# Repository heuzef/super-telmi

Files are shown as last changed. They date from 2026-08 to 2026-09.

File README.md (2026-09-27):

<div align="center">

Logo Super Telmi

 

</div>

---

<details open>
<summary><h3>🇫🇷&nbsp; Français</h3></summary>

<br>

# Super Telmi, la super machine pour Telmi

## Qu’est-ce que la Super Telmi ?

La Super Telmi est une boîte à histoires Open-Source conçue pour émerveiller les enfants, basée sur le système libre [Telmi](https://telmi.fr).

Elle s’appuie sur la console Miyoo, reconnue pour sa simplicité, son prix abordable et sa robustesse, idéale pour les réparations et les améliorations.

Des parents passionnés ont imaginé et testé des améliorations pour offrir le meilleur à leurs enfants.

La Super Telmi rassemble ces innovations et les retours d’expérience concrets des enfants, pour une expérience toujours plus enrichissante.

🎬 [Voir la vidéo de présentation de la Super Telmi](https://www.youtube.com/watch?v=lRGE3fMTku0)

Aperçu de la coque Super Telmi

## Qu’apporte-t-elle de plus ?

* 🔊 **Un vrai haut-parleur de 40 mm**, à la place du minuscule composant d’origine à la qualité sonore décevante.
* 🛡️ **Une coque imprimée en TPU souple**, qui encaisse les chocs, les chutes et les crises de colère.
* 🧲 **Une station d’accueil magnétique**, pour recharger l’appareil d’un simple geste, sans manipuler de connecteur.
* ✂️ **Une simplification du matériel** : les gâchettes, inutiles pour Telmi, sont supprimées.

## Comment se la procurer ?

La Super Telmi est accessible à tous : fabriquez-la vous-même ! Les plans et manuels de fabrication [sont disponibles ici](./diy/DIY_FR.md).

À prévoir pour une fabrication maison : une Miyoo Mini Plus, du matériel de soudure, une imprimante 3D et quelques composants détaillés dans le guide. Comptez environ **20 heures d’impression** au total (≈ 9 h pour la coque, ≈ 10 h pour la station d’accueil).

## Contenu du dépôt

| Dossier | Contenu |
| --- | --- |
| [`diy/`](./diy/) | Les guides de fabrication pas à pas, en [français](./diy/DIY_FR.md), [anglais](./diy/DIY_EN.md), [espagnol](./diy/DIY_ES.md) et [chinois](./diy/DIY_ZH.md). |
| [`files/`](./files/) | Les fichiers 3D : sources CAO (`.f3d`, `.step`), modèles `.3mf`, et fichiers prêts à imprimer pour certaines imprimantes. |

## Contribuer

La Super Telmi a pour vocation d'être en constante amélioration grâce aux idées des parents et enfants.
Il est possible d'apporter votre contribution en [rejoignant le Discord de la communauté Telmi](https://discord.gg/ZTA5FyERbg).

> Les guides existent en plusieurs langues : toute modification apportée à [`DIY_FR.md`](./diy/DIY_FR.md) doit être répercutée dans toutes les autres versions, et inversement.

## Licence

Ce projet est publié sous licence **[CC BY-NC-SA 4.0](./LICENCE.md)** : partage et modifications libres avec attribution, mais **usage commercial interdit sans autorisation préalable**.

</details>

<details>
<summary><h3>🇬🇧&nbsp; English</h3></summary>

<br>

# Super Telmi, the super machine for Telmi

## What is Super Telmi?

Super Telmi is an open-source story box designed to amaze children, based on the free [Telmi](https://telmi.fr) system.

It uses the Miyoo console, known for its simplicity, affordability, and robustness, making it ideal for repairs and upgrades.

Passionate parents have imagined and tested improvements to offer the best for their children.

Super Telmi combines these innovations with real-life feedback from children, for an even more enriching experience.

🎬 [Watch the Super Telmi presentation video](https://www.youtube.com/watch?v=lRGE3fMTku0) (in French)

Preview of the Super Telmi case

## What does it add?

* 🔊 **A real 40 mm speaker**, replacing the tiny original component and its disappointing sound quality.
* 🛡️ **A flexible TPU-printed shell**, which absorbs knocks, drops and temper tantrums.
* 🧲 **A magnetic docking station**, to charge the device in a single gesture, with no connector to fiddle with.
* ✂️ **Simplified hardware**: the triggers, useless for Telmi, are removed.

## How to get it?

Super Telmi is accessible to everyone: do it yourself! Plans and manuals [are available here](./diy/DIY_EN.md).

What you need for a home build: a Miyoo Mini Plus, soldering equipment, a 3D printer and a few components detailed in the guide. Expect around **20 hours of printing** in total (~9h for the shell, ~10h for the docking station).

## Repository contents

| Folder | Contents |
| --- | --- |
| [`diy/`](./diy/) | The step-by-step build guides, in [French](./diy/DIY_FR.md), [English](./diy/DIY_EN.md), [Spanish](./diy/DIY_ES.md) and [Chinese](./diy/DIY_ZH.md). |
| [`files/`](./files/) | The 3D files: CAD sources (`.f3d`, `.step`), `.3mf` models, and ready-to-print files for some printers. |

## Contribute

Super Telmi aims to be constantly improved thanks to the ideas of parents and children.
You can contribute [by joining the Telmi community Discord](https://discord.gg/ZTA5FyERbg).

> The guides exist in several languages: any change made to [`DIY_EN.md`](./diy/DIY_EN.md) must be mirrored in every other version, and vice versa.

## Licence

This project is released under the **[CC BY-NC-SA 4.0](./LICENCE.md)** licence: sharing and modifications are free with attribution, but **commercial use is forbidden without prior permission**.

</details>

<details>
<summary><h3>🇪🇸&nbsp; Español</h3></summary>

<br>

# Super Telmi, la súper máquina para Telmi

## ¿Qué es la Super Telmi?

La Super Telmi es una caja de cuentos de código abierto concebida para maravillar a los niños, basada en el sistema libre [Telmi](https://telmi.fr).

Se apoya en la consola Miyoo, reconocida por su simplicidad, su precio asequible y su robustez, ideal para las reparaciones y las mejoras.

Unos padres apasionados han imaginado y probado mejoras para ofrecer lo mejor a sus hijos.

La Super Telmi reúne estas innovaciones y los comentarios concretos de los niños, para una experiencia cada vez más enriquecedora.

🎬 [Ver el vídeo de presentación de la Super Telmi](https://www.youtube.com/watch?v=lRGE3fMTku0) (en francés)

Vista previa de la carcasa de la Super Telmi

## ¿Qué aporta de más?

* 🔊 **Un altavoz de verdad de 40 mm**, en lugar del minúsculo componente original de calidad de sonido decepcionante.
* 🛡️ **Una carcasa impresa en TPU flexible**, que aguanta los golpes, las caídas y las rabietas.
* 🧲 **Una base de carga magnética**, para recargar el aparato con un simple gesto, sin manipular ningún conector.
* ✂️ **Una simplificación del material**: los gatillos, inútiles para Telmi, se eliminan.

## ¿Cómo conseguirla?

La Super Telmi está al alcance de todos: ¡fabrícala tú mismo! Los planos y manuales de fabricación [están disponibles aquí](./diy/DIY_ES.md).

Lo que hay que prever para una fabricación casera: una Miyoo Mini Plus, material de soldadura, una impresora 3D y algunos componentes detallados en la guía. Cuenta con unas **20 horas de impresión** en total (≈ 9 h para la carcasa, ≈ 10 h para la base de carga).

## Contenido del repositorio

| Carpeta | Contenido |
| --- | --- |
| [`diy/`](./diy/) | Las guías de fabricación paso a paso, en [francés](./diy/DIY_FR.md), [inglés](./diy/DIY_EN.md), [español](./diy/DIY_ES.md) y [chino](./diy/DIY_ZH.md). |
| [`files/`](./files/) | Los archivos 3D: fuentes CAD (`.f3d`, `.step`), modelos `.3mf` y archivos listos para imprimir para algunas impresoras. |

## Contribuir

La Super Telmi tiene la vocación de mejorar constantemente gracias a las ideas de los padres y de los niños.
Puedes aportar tu contribución [uniéndote al Discord de la comunidad Telmi](https://discord.gg/ZTA5FyERbg).

> Las guías existen en varios idiomas: cualquier modificación realizada en [`DIY_ES.md`](./diy/DIY_ES.md) debe replicarse en todas las demás versiones, y a la inversa.

## Licencia

Este proyecto se publica bajo licencia **[CC BY-NC-SA 4.0](./LICENCE.md)**: compartir y modificar libremente con atribución, pero **uso comercial prohibido sin autorización previa**.

</details>

<details>
<summary><h3>🇨🇳&nbsp; 中文</h3></summary>

<br>

# Super Telmi，为 Telmi 打造的超级机器

## 什么是 Super Telmi？

Super Telmi 是一款开源故事机，基于自由系统 [Telmi](https://telmi.fr)，旨在带给孩子们惊喜。

它以 Miyoo 掌机为基础，这款掌机以简单、价格实惠和坚固耐用著称，非常适合维修和改装。

一群充满热情的家长构想并测试了各种改进，只为给自己的孩子最好的。

Super Telmi 汇集了这些创新，以及孩子们在实际使用中的反馈，带来愈发丰富的体验。

🎬 [观看 Super Telmi 介绍视频](https://www.youtube.com/watch?v=lRGE3fMTku0)（法语）

Super Telmi 外壳预览

## 它有哪些提升？

* 🔊 **一只真正的 40 mm 扬声器**，取代音质令人失望的原装微型元件。
* 🛡️ **柔性 TPU 打印外壳**，能够承受磕碰、跌落和闹脾气。
* 🧲 **磁吸充电底座**，一个动作即可充电，无需插拔接头。
* ✂️ **精简硬件**：Telmi 用不到的扳机键已被移除。

## 如何获得？

Super Telmi 人人可得：自己动手做吧！图纸和制作手册[可在此处获取](./diy/DIY_ZH.md)。

自行制作需要准备：一台 Miyoo Mini Plus、焊接工具、一台 3D 打印机，以及指南中详细列出的若干元件。全部打印时间约为 **20 小时**（外壳约 9 小时，充电底座约 10 小时）。

## 仓库内容

| 目录 | 内容 |
| --- | --- |
| [`diy/`](./diy/) | 分步制作指南，提供[法语](./diy/DIY_FR.md)、[英语](./diy/DIY_EN.md)、[西班牙语](./diy/DIY_ES.md)和[中文](./diy/DIY_ZH.md)版本。 |
| [`files/`](./files/) | 3D 文件：CAD 源文件（`.f3d`、`.step`）、`.3mf` 模型，以及部分打印机的即打即用文件。 |

## 参与贡献

Super Telmi 立志依靠家长和孩子们的想法不断改进。
欢迎[加入 Telmi 社区 Discord](https://discord.gg/ZTA5FyERbg) 参与贡献。

> 本指南提供多个语言版本：对 [`DIY_ZH.md`](./diy/DIY_ZH.md) 所做的任何修改都必须同步到其他所有语言版本，反之亦然。

## 许可协议

本项目基于 **[CC BY-NC-SA 4.0](./LICENCE.md)** 许可协议发布：可自由分享和修改，但须署名，且**未经事先许可禁止商业使用**。

</details>

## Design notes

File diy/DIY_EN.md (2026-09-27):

<!-- This guide exists in several languages. Any change made here must be mirrored in DIY_FR.md, DIY_ES.md and DIY_ZH.md. -->

Welcome to the Super Telmi build guide. You are about to give your children the very best storytelling box there is not only because of the love you will put into making them this beautiful gift, but also because of the outstanding durability of the hardware offered here, as well as the unlimited potential offered by Telmi.

# Required equipment

* Electronic soldering equipment
* 3D printer
* [A Miyoo Mini Plus](https://wiki.telmi.fr/achats/miyoo_mini_plus)

# Parts to buy
* [40 mm 8 ohm 3 W speaker](https://fr.aliexpress.com/item/1005002679785627.html)
* [Electrical wire](https://fr.aliexpress.com/item/1005005450270866.html)
* [M2 and M3 screws and nuts](https://fr.aliexpress.com/item/1005007159750547.html)
* [250 g spool of TPU filament](https://fr.aliexpress.com/item/1005007707597137.html)
* [Cable with magnetic USB-C tip](https://fr.aliexpress.com/item/1005009401790316.html)
* [4 round neodymium magnets, 10x3 mm](https://fr.aliexpress.com/item/1005009749865836.html)
* [Cyanoacrylate glue](https://fr.aliexpress.com/item/1005008517608338.html)
* [Cable ties](https://fr.aliexpress.com/item/1005009405351665.html)

# Build

Feel free to come and meet the community on [Discord](https://discord.gg/ZTA5FyERbg) before you start building!

Your feedback is invaluable in helping this project improve continuously.

## 3D printing the parts



The 3D files are available [HERE](../files/) and must be printed in TPU for shock absorption.

For the main shell, an infill of at least 25% to 30% is recommended to make sure the Super Telmi is as resistant as possible to knocks, drops, temper tantrums, or any other creative misuse aimed at doing violence to a sibling.

A higher infill would risk making the shell too rigid, and therefore less effective at absorbing impacts.

## Disassembling the Miyoo

The first step is to remove the battery, through the small hatch at the back of the Miyoo.
It comes out fairly easily using small pliers, gently pull out the 2-pin connector.

Let's start taking off the Miyoo's back shell. You will spot 6 small M2 screws.

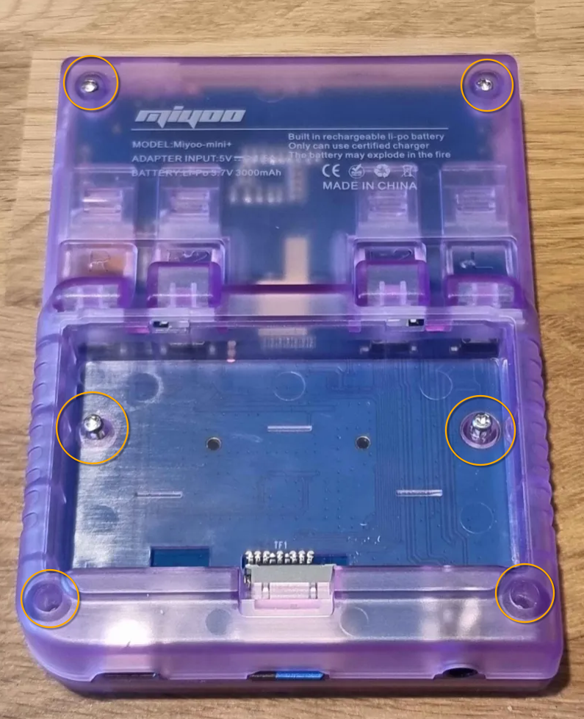
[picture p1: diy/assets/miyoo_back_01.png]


Once they are removed, take off the shell (by prying it gently), you will not need it anymore.

The screen is held by a ribbon cable, which you need to disconnect. To do so, locate the small white line on the motherboard and unlock it by prying it open. Then gently pull the ribbon cable out to disconnect the screen.

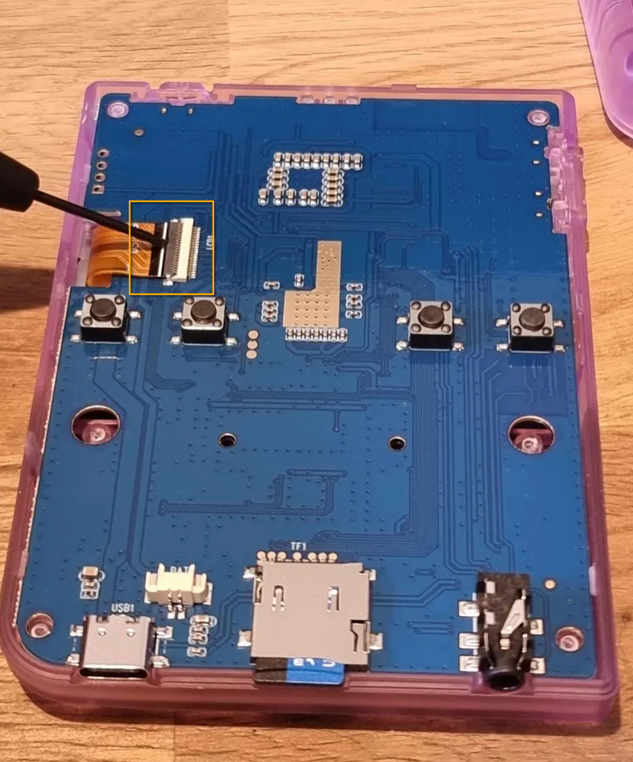
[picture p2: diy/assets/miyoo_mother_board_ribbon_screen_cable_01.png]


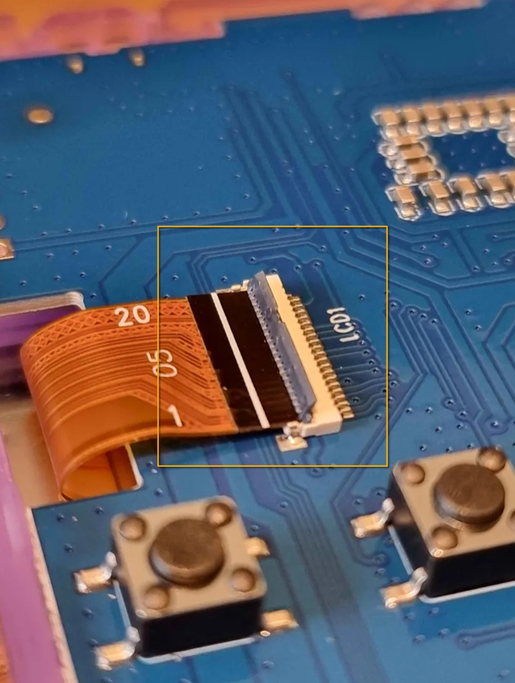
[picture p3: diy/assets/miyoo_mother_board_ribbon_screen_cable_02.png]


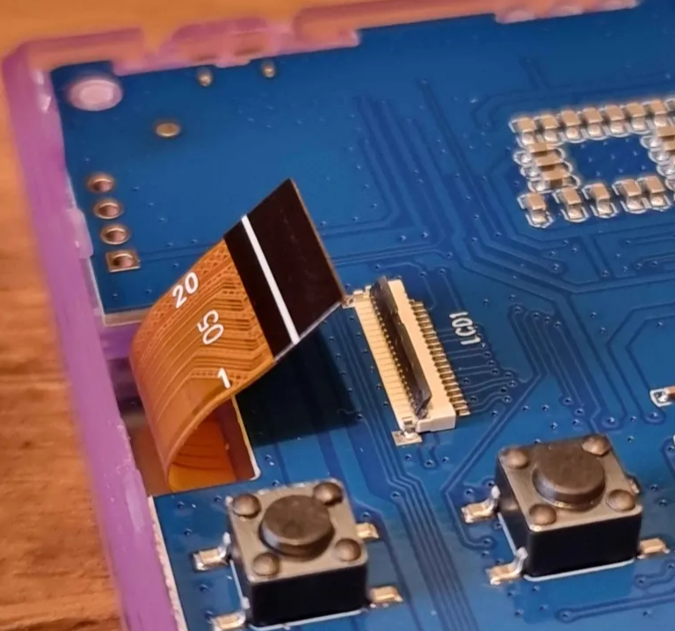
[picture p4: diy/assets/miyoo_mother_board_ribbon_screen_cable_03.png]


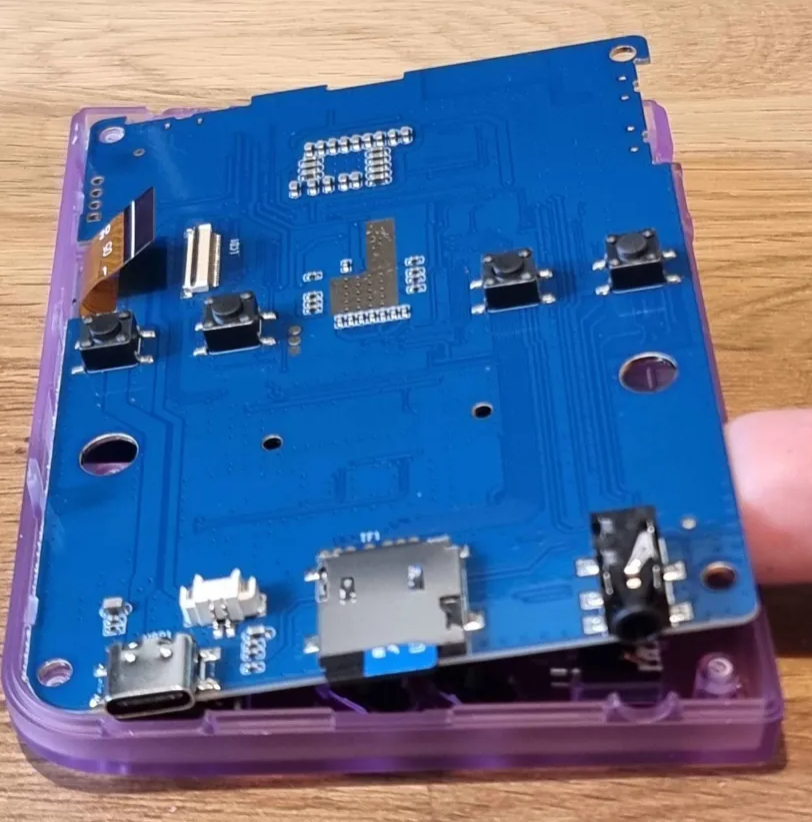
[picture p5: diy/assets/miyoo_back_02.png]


Now take out all the small parts of the Miyoo so you can look them over and get familiar with them:

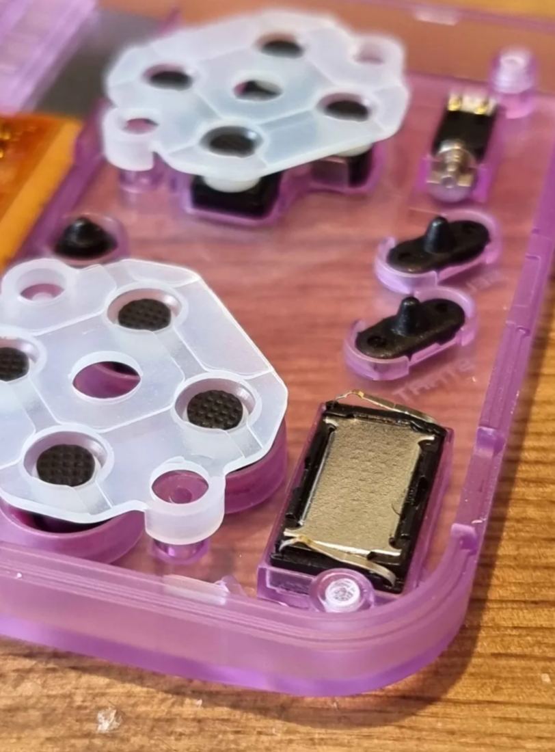
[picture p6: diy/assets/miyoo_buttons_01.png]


* The buttons
* The D-pads and their silicone supports
* The triggers (which will no longer be used, as they are unnecessary for Telmi)
* And finally the power and volume control buttons (which are barely held in place, as you will see)

Set all of this carefully aside.

## Preparing the speaker

It is now time to remove the speaker, located at the bottom right. This little component offers very poor sound quality. It makes a simple pressure contact on the motherboard through its two legs, and that is exactly what we are going to reproduce with our 40 mm speaker.

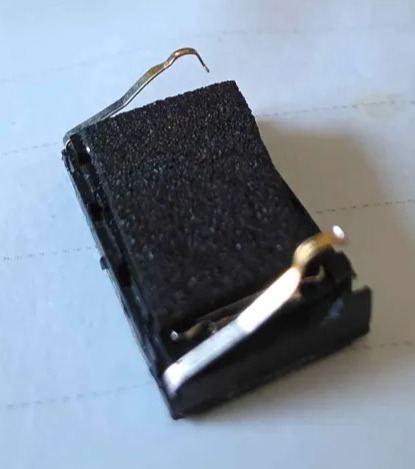
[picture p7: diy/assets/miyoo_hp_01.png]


Now that all the components are accessible, you can set aside the back shell, the triggers and the original speaker: they are of no use.

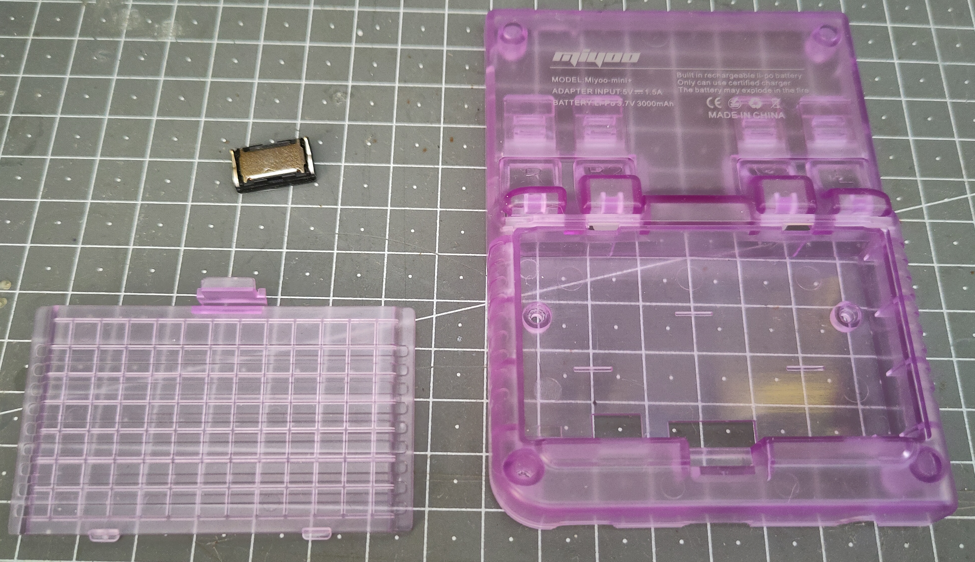
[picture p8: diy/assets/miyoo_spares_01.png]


Using wires roughly 20 cm long, solder them to the speaker.

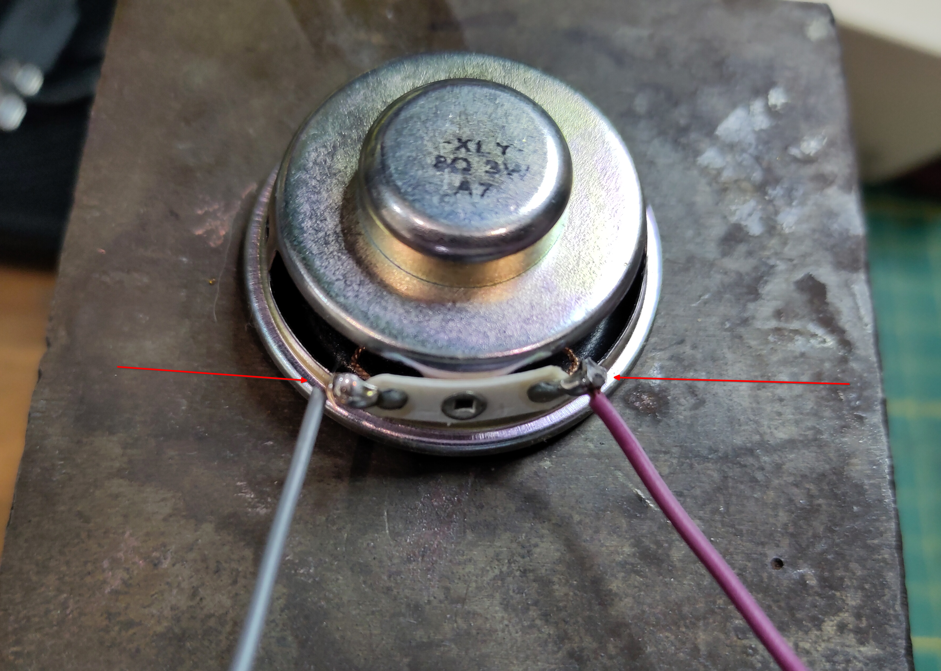
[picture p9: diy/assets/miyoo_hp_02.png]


Then feed the wires through the speaker hole in the Super Telmi case. Tip: you can fit a piece of foam here to seat the speaker, which will improve both the acoustics and the stability.

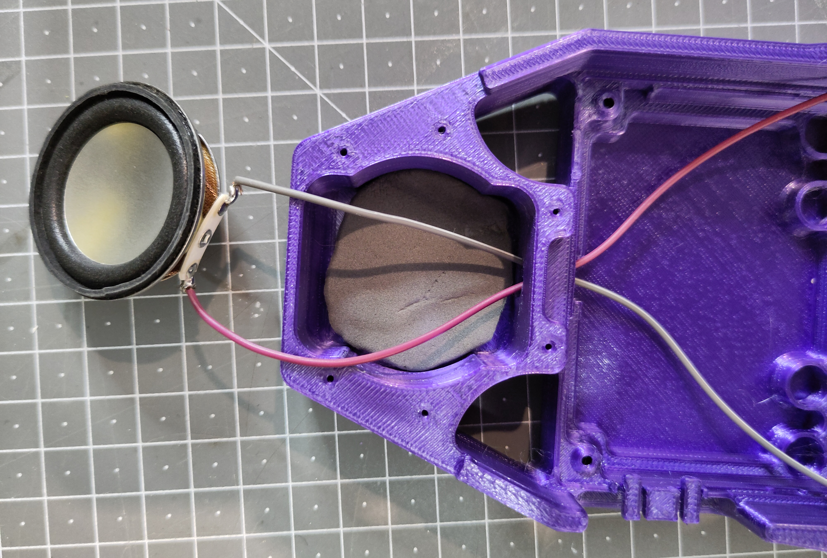
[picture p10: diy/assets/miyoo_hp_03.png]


Now gently turn the motherboard over to start soldering onto the speaker connectors. They are at the bottom right, marked "SPK1".

Feel free to run an audio test by powering on the motherboard while pressing against the contact pads before soldering. Don't worry, the voltage of the device is very low, you are in no danger.

> The polarity of the speaker connections does not matter here.

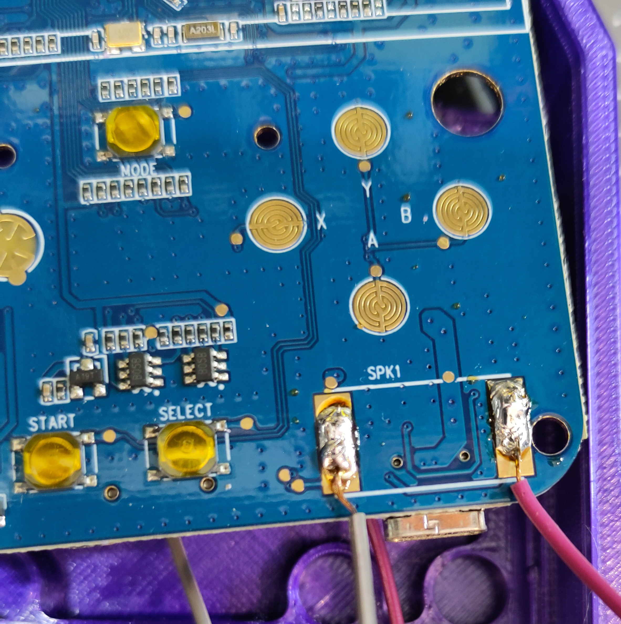
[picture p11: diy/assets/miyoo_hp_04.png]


## Assembling the Super Telmi

The speaker is ready, so you can now carefully position the motherboard inside the case. Slide the speaker wires along the edge of the Miyoo.
You can use a bit of adhesive tape to hold the wiring in place all the way to the speaker.

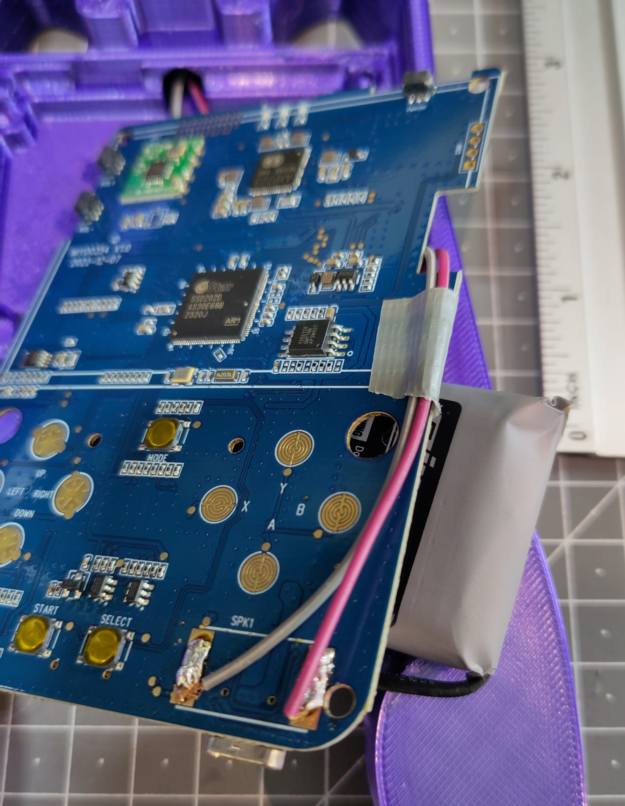
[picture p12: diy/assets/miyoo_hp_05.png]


Once you are happy with the speaker installation and the placement of the motherboard, calmly reassemble all the small components. Be gentle, this takes patience. The buttons are particularly unstable, so stay attentive.

A good tip is to use masking tape to hold all the components in place before starting the assembly.

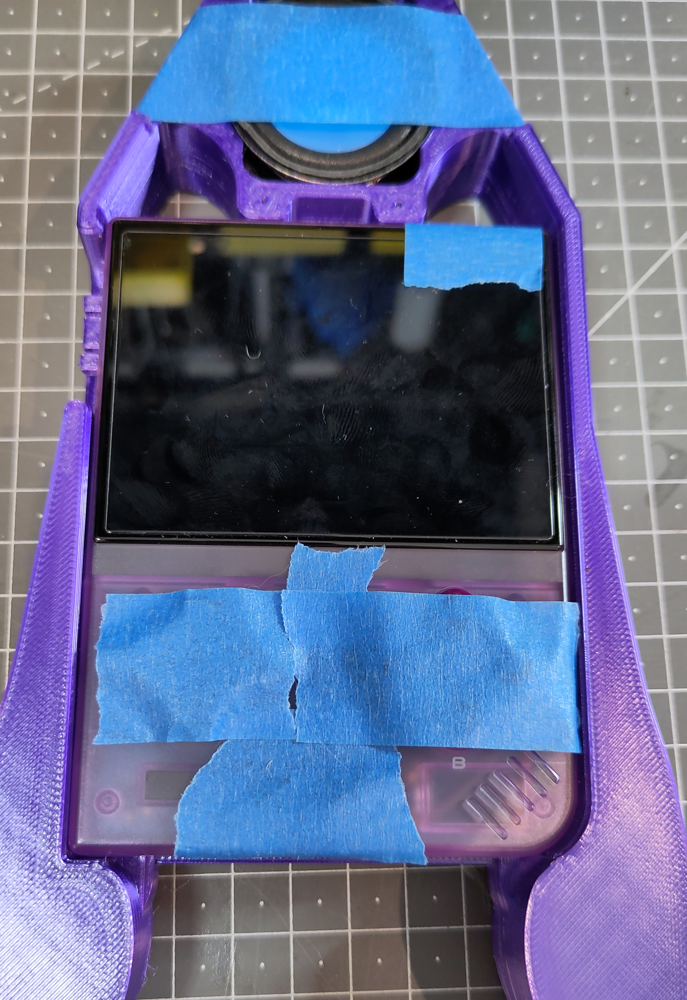
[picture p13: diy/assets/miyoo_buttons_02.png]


Everything in place? Position the back panel, hold it, then gently turn the machine over.
You can reuse the original screws to tighten it all up. Tighten in a crosswise pattern.

Finally, fit the speaker front panel.



Test everything! You should now have a Super Telmi ready to use.



Have fun customising the space on the back if you like, for example the child's first name, your contact details in case the device gets lost, etc. You can edit the text directly in your favourite slicer thanks to the 3MF file.

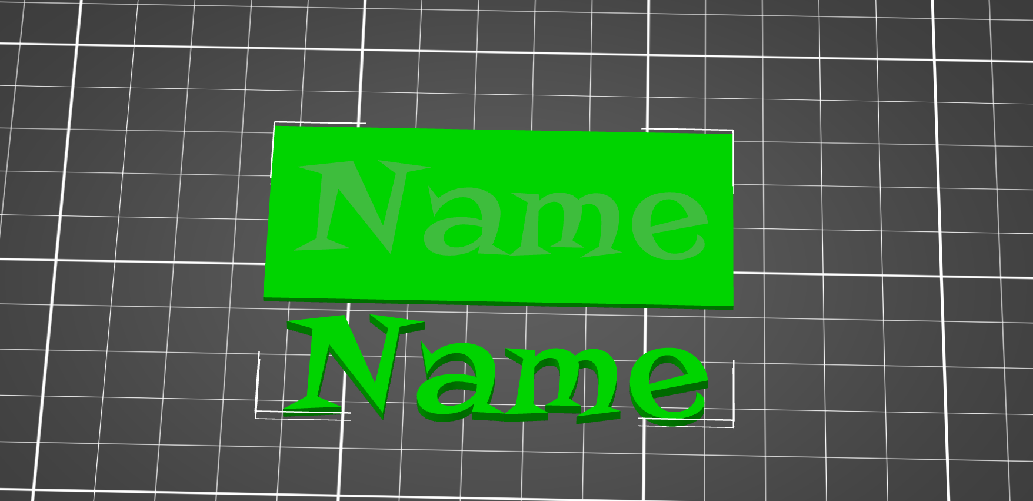
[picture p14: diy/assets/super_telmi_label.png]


## Building the docking station

Once your station has been printed and cleaned up, you can apply one drop (no more) of cyanoacrylate glue in each hole made for the neodymium magnets.

> Double-check the polarity, orientation matters, before sealing them permanently.

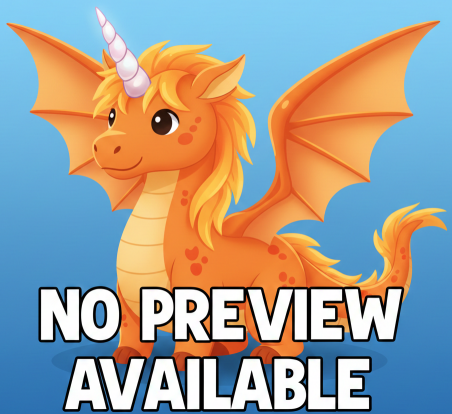
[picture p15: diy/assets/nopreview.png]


Now, insert an M3 bolt from the back of the station into the hole provided for it.



With the bolt in place, fit a small cable tie around it, which you can partially close, leaving it just open enough to pass the head of the USB-C cable and its magnetic tip through.



Once you have carefully worked out the ideal position with the Super Telmi, tighten the cable tie firmly to hold the cable and its magnetic tip permanently in place.



Cut off the excess cable tie with wire cutters, then tuck the USB cable along the slot provided for it.



Congratulations, your Super Telmi is finished. All that's left is to wrap it up as a gift 🎁

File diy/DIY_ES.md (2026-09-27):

<!-- Esta guía existe en varios idiomas. Cualquier modificación realizada aquí debe replicarse en DIY_FR.md, DIY_EN.md y DIY_ZH.md. -->

Bienvenido a la guía de fabricación de la Super Telmi. Estás a punto de regalar a tus hijos lo mejor que existe en materia de cajas de cuentos, no solo por el cariño que pondrás en crear este bonito regalo, sino también por la enorme resistencia del material que se te ofrece aquí, así como por el potencial ilimitado que aporta Telmi.

# Material necesario

* Equipo de soldadura electrónica
* Impresora 3D
* [Una Miyoo Mini Plus](https://wiki.telmi.fr/achats/miyoo_mini_plus)

# Compras a prever
* [Altavoz de 40 mm 8 ohmios 3 W](https://fr.aliexpress.com/item/1005002679785627.html)
* [Cables eléctricos](https://fr.aliexpress.com/item/1005005450270866.html)
* [Tornillos y tuercas M2 y M3](https://fr.aliexpress.com/item/1005007159750547.html)
* [Bobina de filamento TPU de 250 g](https://fr.aliexpress.com/item/1005007707597137.html)
* [Cable con conector USB-C magnético](https://fr.aliexpress.com/item/1005009401790316.html)
* [4 imanes de neodimio redondos de 10x3 mm](https://fr.aliexpress.com/item/1005009749865836.html)
* [Pegamento de cianoacrilato](https://fr.aliexpress.com/item/1005008517608338.html)
* [Bridas](https://fr.aliexpress.com/item/1005009405351665.html)

# Fabricación

¡No dudes en conocer a la comunidad en [Discord](https://discord.gg/ZTA5FyERbg) antes de lanzarte a la fabricación!

Tus comentarios son valiosos para permitir la mejora continua de este proyecto.

## Impresión 3D de las piezas



Los archivos 3D están disponibles [AQUÍ](../files/) y deben imprimirse en TPU para la absorción de los impactos.

Para la carcasa principal, se recomienda un relleno de al menos el 25 % al 30 % para asegurarse de que la Super Telmi sea lo más resistente posible a los golpes, las caídas, las rabietas o cualquier uso abusivo desviado para agredir a los hermanos.

Un relleno mayor correría el riesgo de volver la carcasa demasiado rígida, absorbiendo entonces los impactos con menos eficacia.

## Desmontaje de la Miyoo

La primera acción es retirar la batería, a través de la pequeña tapa de la parte trasera de la Miyoo.
Esta se quita con bastante facilidad con unas pinzas pequeñas, retira suavemente el conector de 2 pines.

Empecemos el desmontaje de la carcasa trasera de la Miyoo. Vas a poder localizar 6 tornillos M2 pequeños.



Una vez retirados, quita la carcasa (haciendo palanca) muy suavemente, esta ya no te será útil.

La pantalla está sujeta por un cable plano, que debes desconectar. Para ello, localiza la pequeña línea blanca de la placa base y procede a desbloquearla haciendo palanca. Luego extrae con cuidado el cable plano para desconectar la pantalla.









Ahora, saca todas las piezas pequeñas de la Miyoo para verlas y familiarizarte con ellas:



* Los botones
* Las cruces direccionales y sus soportes de silicona
* Los gatillos (que ya no se utilizarán, pues son inútiles para Telmi)
* Y por último los botones de control de encendido y de volumen (que apenas están sujetos, como vas a comprobar)

Aparta todo esto con cuidado.

## Preparación del altavoz

Es el momento de retirar el altavoz, situado abajo a la derecha, este pequeño componente ofrece una calidad de sonido bastante pobre. Este realiza, mediante sus dos patas, un simple contacto por presión sobre la placa base, y eso es lo que vamos a reproducir con nuestro altavoz de 40 mm.



Ahora que todos los componentes están accesibles, puedes apartar la carcasa trasera, los gatillos y el altavoz original: son inútiles.



Con cables de aproximadamente 20 cm, suéldalos al altavoz.



Luego, pasa los cables por el orificio del altavoz de la Super Telmi. Consejo: puedes alojar aquí un trozo de espuma para asentar el altavoz, lo que mejorará la acústica y la estabilidad.



Ahora, dale la vuelta con cuidado a la placa base para empezar a soldar en los contactos del altavoz. Están abajo a la derecha, indicados como «SPK1».

No dudes en hacer una prueba de audio encendiendo la placa base mientras mantienes una presión sobre las superficies de contacto antes de soldar. Sin preocupación, la tensión del dispositivo es muy baja, no corres ningún riesgo.

> Aquí la polaridad de las conexiones del altavoz no tiene importancia.



## Montaje de la Super Telmi

El altavoz está listo, así que vas a poder colocar con cuidado la placa base en la carcasa. Desliza los cables del altavoz por el borde de la Miyoo.
Puedes usar un poco de cinta adhesiva para estabilizar la colocación del cableado hasta el altavoz.



Una vez satisfecho con el montaje del altavoz y la colocación de la placa base, vuelve a montar con calma todos los componentes pequeños. Sé delicado, esto requiere paciencia. Los botones son especialmente inestables, presta atención.

Un buen truco es usar cinta de carrocero para estabilizar todos los componentes antes de empezar el montaje.



¿Todo en su sitio? Coloca la cara trasera, sujétala y luego dale la vuelta a la máquina despacio.
Vas a poder reutilizar los tornillos originales para proceder al apriete. Aprieta en cruz.

Por último, fija la tapa del altavoz.



¡Pruébalo todo! A estas alturas deberías tener una Super Telmi lista para usar.



Diviértete personalizando el espacio de la parte trasera si lo deseas, por ejemplo con el nombre del niño, tus datos de contacto en caso de pérdida del aparato, etc. Es posible editar el texto directamente en tu laminador favorito gracias al archivo 3MF.



## Fabricación de la base de carga

Una vez impresa y limpiada tu base, puedes aplicar una gota (no más) de pegamento de cianoacrilato en cada orificio previsto para alojar los imanes de neodimio.

> Comprueba bien la polaridad, el sentido es importante, antes de sellarlos definitivamente.



Ahora, inserta un tornillo M3 desde la parte trasera de la base en el orificio previsto a tal efecto.



Con este en su sitio, coloca a su alrededor una brida pequeña que puedes precerrar, dejándola justo lo bastante abierta para pasar el cabezal del cable USB-C y el conector magnético.



Una vez bien medida la posición ideal con la Super Telmi, aprieta firmemente la brida para mantener la posición del cable y su conector magnético definitivamente en su sitio.



Corta el excedente de la brida con unos alicates de corte, luego desliza el cable USB a lo largo de la ranura prevista a tal efecto.



¡Enhorabuena, has terminado la Super Telmi! Ya solo queda envolverla para regalar 🎁

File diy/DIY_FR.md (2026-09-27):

<!-- Ce guide existe en plusieurs langues. Toute modification apportée ici doit être répercutée dans DIY_EN.md, DIY_ES.md et DIY_ZH.md. -->

Bienvenue dans le guide de fabrication de la Super Telmi, vous vous apprêtez à offrir à vos enfants ce qui existe de mieux en matière de boîte à histoires, non seulement par l'amour que vous mettrez à leur concevoir ce beau cadeau, mais aussi par la très forte résilience qui vous est offerte ici sur le matériel, ainsi que le potentiel illimité offert par Telmi.

# Matériel requis

* Équipement de soudure électronique
* Imprimante 3D
* [Une Miyoo Mini Plus](https://wiki.telmi.fr/achats/miyoo_mini_plus)

# Achats à prévoir
* [Haut-parleur 40 mm 8 ohms 3 W](https://fr.aliexpress.com/item/1005002679785627.html)
* [Fils électriques](https://fr.aliexpress.com/item/1005005450270866.html)
* [Vis et écrous M2 et M3](https://fr.aliexpress.com/item/1005007159750547.html)
* [Bobine de filament TPU 250 g](https://fr.aliexpress.com/item/1005007707597137.html)
* [Câble avec embout USB-C magnétique](https://fr.aliexpress.com/item/1005009401790316.html)
* [4 aimants néodyme ronds 10x3 mm](https://fr.aliexpress.com/item/1005009749865836.html)
* [Colle cyanoacrylate](https://fr.aliexpress.com/item/1005008517608338.html)
* [Colliers de serrage](https://fr.aliexpress.com/item/1005009405351665.html)

# Fabrication

N'hésitez pas à rencontrer la communauté sur [Discord](https://discord.gg/ZTA5FyERbg) avant de vous lancer dans la fabrication !

Vos retours d'expérience sont précieux pour permettre l'amélioration continue de ce projet.

## Impression 3D des pièces



Les fichiers 3D sont disponibles [ICI](../files/) et doivent être imprimés avec du TPU pour l'absorption des chocs.

Pour la coque principale, il est recommandé d'avoir un remplissage d'au moins 25 % à 30 % pour s'assurer que la Super Telmi soit la plus résistante possible aux chocs, chutes, crises de colère ou toute utilisation abusive détournée pour violenter la fratrie.

Un remplissage plus important risquerait de rendre la coque trop solide, absorbant alors moins efficacement les chocs.

## Démontage de la Miyoo

La première action est de retirer la batterie, via la petite trappe à l'arrière de la Miyoo.
Cette dernière est assez simple à enlever à l'aide d'une petite pince, retirez doucement le connecteur 2 pins.

Commençons le démontage de la coque arrière de la Miyoo. Vous allez pouvoir repérer 6 petites vis M2.



Une fois enlevées, retirez la coque (avec un effet de levier) tout doucement, cette dernière ne vous sera plus utile.

L'écran est maintenu par une nappe, il vous faut la déconnecter. Pour cela, repérez la petite ligne blanche sur la carte mère et procédez à un déverrouillage par effet de levier. Puis sortez délicatement la nappe pour débrancher l'écran.









À présent, sortez toutes les petites pièces de la Miyoo pour en prendre connaissance et vous familiariser avec :



* Les boutons
* Les croix directionnelles et leurs supports en silicone
* Les gâchettes (qui ne seront plus utilisées car inutiles pour Telmi)
* Et enfin les boutons de contrôle d'allumage et de volume (qui ne tiennent pas à grand-chose comme vous allez le constater)

Mettez tout ceci de côté soigneusement.

## Préparation du haut-parleur

Il est temps de retirer le haut-parleur, situé en bas à droite, ce petit composant offre une bien piètre qualité sonore. Ce dernier effectue via ses deux pattes un simple contact par pression sur la carte mère, c'est ce que nous allons reproduire avec notre haut-parleur de 40 mm.



Maintenant que tous les composants sont disponibles, vous pouvez mettre de côté la coque arrière, les gâchettes et le haut-parleur d'origine : ils sont inutiles.



Avec des câbles d'approximativement 20 cm, effectuez une soudure sur le haut-parleur.



Puis, glissez les câbles dans le trou du haut-parleur de la Super Telmi. Astuce : vous pouvez loger un bout de mousse pour accueillir le haut-parleur ici, cela améliorera l'acoustique et la stabilité.



À présent, retournez délicatement la carte mère pour commencer la soudure sur les connecteurs du haut-parleur. Ils sont en bas à droite, indiqués « SPK1 ».

N'hésitez pas à faire un test audio en allumant la carte mère tout en maintenant une pression sur les surfaces de contact avant de souder. Pas d'inquiétude, la tension du périphérique est très faible, vous ne risquez rien.

> La polarité des connexions du haut-parleur n'a pas d'importance ici.



## Montage de la Super Telmi

Le haut-parleur est prêt, vous allez pouvoir positionner délicatement la carte mère dans le boîtier. Glissez les câbles du haut-parleur sur le bord de la Miyoo.
Vous pouvez utiliser un peu de ruban adhésif pour stabiliser le placement du câblage jusqu'au haut-parleur.



Une fois satisfait du montage du haut-parleur et du placement de la carte mère, remontez tranquillement tous les petits composants. Soyez délicat, cela demande de la patience. Les boutons sont particulièrement instables, soyez attentif.

Une bonne astuce est d'utiliser du ruban de masquage pour stabiliser tous les composants avant de commencer le montage.



Tout est en place ? Positionnez la face arrière, maintenez-la, puis retournez la machine doucement.
Vous allez pouvoir réutiliser les vis d'origine pour procéder au serrage. Serrez en croix.

Enfin, fixez la façade pour le haut-parleur.



Testez tout ! Vous devriez avoir une Super Telmi prête à l'usage à ce stade.



Amusez-vous à personnaliser l'emplacement à l'arrière si vous le souhaitez, par exemple le prénom de l'enfant, vos coordonnées en cas de perte de l'appareil, etc. Il est possible d'éditer le texte directement dans votre slicer favori grâce au fichier 3MF.



## Fabrication de la station d'accueil

Une fois votre station imprimée et nettoyée, vous pouvez appliquer une goutte (pas plus) de colle cyanoacrylate dans chaque trou prévu pour l'accueil des aimants néodyme.

> Vérifiez bien la polarité, le sens est important, avant de les sceller définitivement.



À présent, insérez un boulon M3 depuis l'arrière de la station dans le trou prévu à cet effet.



Ce dernier en place, insérez un petit collier de serrage autour, que vous pouvez pré-fermer en laissant juste assez d'ouverture pour passer la tête du câble USB-C et l'embout aimanté.



Une fois la position idéale bien mesurée avec la Super Telmi, serrez fermement le collier de serrage pour maintenir la position du câble et son embout aimanté définitivement en place.



Coupez l'excédent du collier avec une pince coupante, puis glissez le câble USB le long de la fente prévue à cet effet.



Félicitations, vous avez terminé la Super Telmi. Il ne reste plus qu'à emballer pour offrir 🎁

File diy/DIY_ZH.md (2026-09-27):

<!-- 本指南提供多个语言版本。在此处所做的任何修改都必须同步到 DIY_FR.md、DIY_EN.md 和 DIY_ES.md。 -->

欢迎阅读 Super Telmi 制作指南。您即将为孩子打造一台现有最出色的故事机，这不仅因为您在制作这份礼物时投入的爱，也因为这里为您提供的硬件具备极强的耐用性，以及 Telmi 所带来的无限潜力。

# 所需设备

* 电子焊接工具
* 3D 打印机
* [一台 Miyoo Mini Plus](https://wiki.telmi.fr/achats/miyoo_mini_plus)

# 需要采购的零件
* [40 mm 8 欧姆 3 W 扬声器](https://fr.aliexpress.com/item/1005002679785627.html)
* [电线](https://fr.aliexpress.com/item/1005005450270866.html)
* [M2 和 M3 螺丝与螺母](https://fr.aliexpress.com/item/1005007159750547.html)
* [250 g TPU 耗材卷](https://fr.aliexpress.com/item/1005007707597137.html)
* [带磁吸 USB-C 接头的数据线](https://fr.aliexpress.com/item/1005009401790316.html)
* [4 颗圆形钕磁铁，10x3 mm](https://fr.aliexpress.com/item/1005009749865836.html)
* [氰基丙烯酸酯胶水（快干胶）](https://fr.aliexpress.com/item/1005008517608338.html)
* [尼龙扎带](https://fr.aliexpress.com/item/1005009405351665.html)

# 制作

在动手制作之前，欢迎先到 [Discord](https://discord.gg/ZTA5FyERbg) 上与社区成员交流！

您的反馈非常宝贵，有助于本项目的持续改进。

## 3D 打印零件



3D 文件可在[此处](../files/)获取，必须使用 TPU 打印以吸收冲击。

对于主外壳，建议采用至少 25% 到 30% 的填充率，以确保 Super Telmi 能尽可能地承受磕碰、跌落、闹脾气，或任何被拿来对兄弟姐妹动粗的滥用行为。

填充率过高反而会使外壳太硬，吸收冲击的效果变差。

## 拆解 Miyoo

第一步是通过 Miyoo 背面的小盖板取出电池。
用一把小镊子就能比较轻松地取下，请轻轻拔出 2 针接插件。

现在开始拆卸 Miyoo 的后壳。您会看到 6 颗 M2 小螺丝。



螺丝取下后，用撬的方式非常轻柔地取下后壳，之后不再需要它。

屏幕由一根排线固定，需要将其断开。为此，请找到主板上的白色小卡扣，用撬的方式将其解锁。然后小心抽出排线，断开屏幕的连接。









现在，把 Miyoo 的所有小零件取出来，看一遍并熟悉它们：



* 按键
* 十字方向键及其硅胶支架
* 扳机键（Telmi 用不到，因此不再使用）
* 最后是电源和音量控制键（如您将会发现的，它们几乎没有被固定住）

请把这些零件小心地放到一边。

## 准备扬声器

现在该拆下位于右下角的扬声器了，这个小元件的音质相当差。它通过两个金属脚以简单的压力接触主板，而这正是我们要用 40 mm 扬声器复现的方式。



既然所有元件都已取出，您可以把后壳、扳机键和原装扬声器放到一边：它们已无用处。



用大约 20 cm 长的电线焊接到扬声器上。



然后，把电线穿过 Super Telmi 外壳上的扬声器孔。小技巧：可以在这里垫一小块泡棉来承托扬声器，这会同时改善音效和稳定性。



现在，小心地把主板翻过来，开始焊接扬声器的接点。它们位于右下角，标有「SPK1」。

焊接之前，不妨先给主板通电，同时把线头压在接触面上做一次音频测试。不用担心，本设备的电压很低，不会有任何危险。

> 此处扬声器接线的极性无关紧要。



## 组装 Super Telmi

扬声器准备好了，现在可以把主板小心地放入外壳中。把扬声器的电线沿着 Miyoo 的边缘理好。
可以用一点胶带把走线一直固定到扬声器处。



对扬声器的安装和主板的位置满意之后，从容地把所有小零件装回去。请轻柔操作，这需要耐心。按键特别容易移位，请多加注意。

一个好办法是在开始组装前，用美纹纸胶带把所有零件固定住。



都装好了吗？把后盖放上，按住它，然后轻轻把机器翻过来。
您可以使用原装螺丝进行紧固。请对角交叉拧紧。

最后，装上扬声器的面板。



全部测试一遍！此时您应该已经拥有一台可以使用的 Super Telmi 了。



如果愿意，可以在背面的区域上自由发挥，比如刻上孩子的名字、您的联系方式（以防设备丢失）等等。借助 3MF 文件，您可以直接在常用的切片软件中编辑这段文字。



## 制作充电底座

底座打印并清理干净后，可以在每个用于安放钕磁铁的孔中滴一滴（不要多）氰基丙烯酸酯胶水。

> 在永久固定之前，请务必检查磁极，方向很重要。



现在，从底座背面把一颗 M3 螺栓插入预留的孔中。



螺栓到位后，在其周围套上一根小扎带并预先收紧，只留出刚好能穿过 USB-C 线头和磁吸接头的开口。



用 Super Telmi 仔细确认好理想位置后，用力收紧扎带，把线缆和它的磁吸接头永久固定在该位置。



用斜口钳剪掉扎带多余的部分，然后把 USB 线塞进预留的槽中。



恭喜，您已经完成了 Super Telmi。剩下的就只有把它包装起来送出去了 🎁

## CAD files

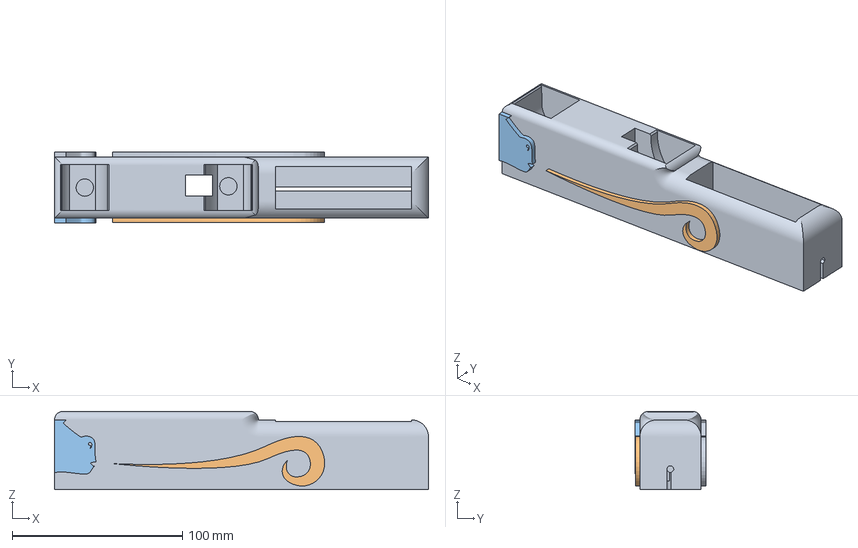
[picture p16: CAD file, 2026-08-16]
files/3MF/super_telmi_dock.3mf
220.0 x 42.0 x 46.0 mm
Corps1
Corps2
Corps3

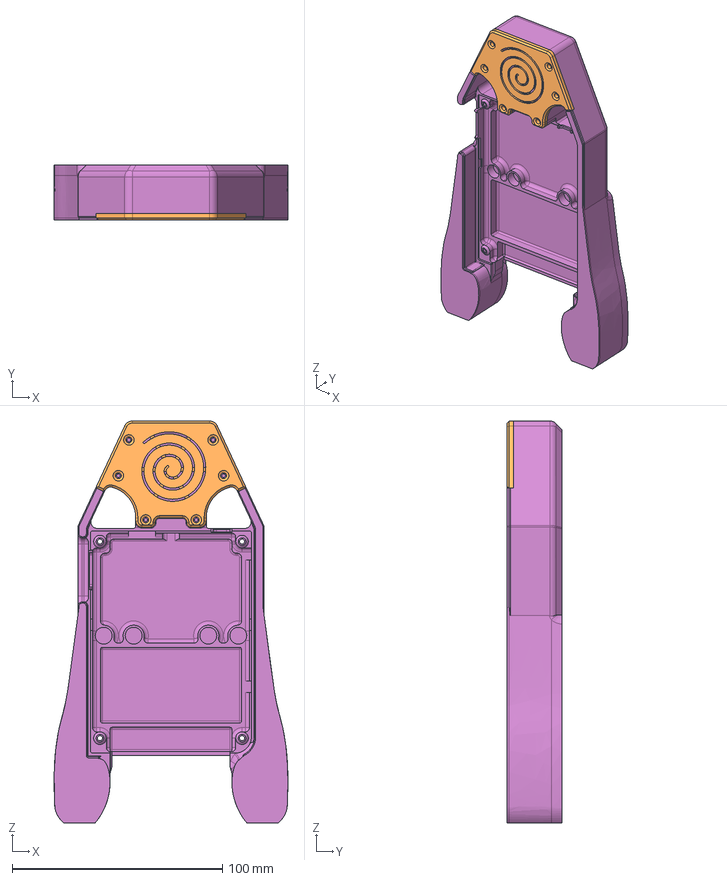
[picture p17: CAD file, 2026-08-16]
files/super_telmi.step
111.1 x 26.0 x 191.0 mm

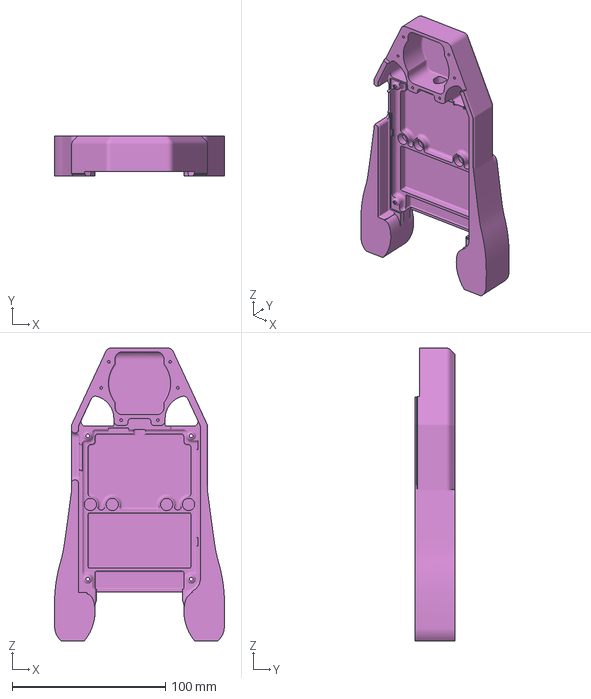
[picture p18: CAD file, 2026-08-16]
files/3MF/super_telmi_case.3mf
111.1 x 26.0 x 191.0 mm

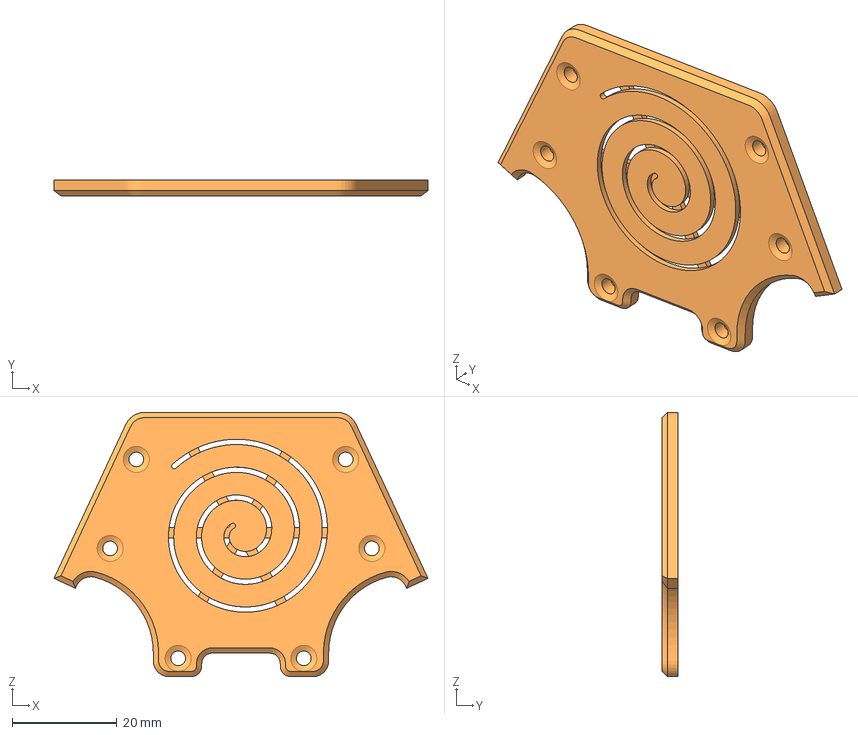
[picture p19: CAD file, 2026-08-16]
files/3MF/super_telmi_cover.3mf
71.5 x 3.00 x 50.5 mm

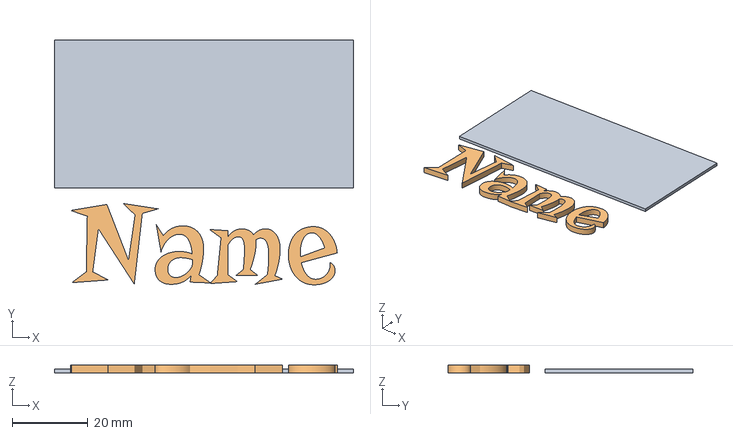
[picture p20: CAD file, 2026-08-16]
files/3MF/super_telmi_label.3mf
79.0 x 64.6 x 2.00 mm
Texte - Texte embossé

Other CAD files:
files/super_telmi.f3d
